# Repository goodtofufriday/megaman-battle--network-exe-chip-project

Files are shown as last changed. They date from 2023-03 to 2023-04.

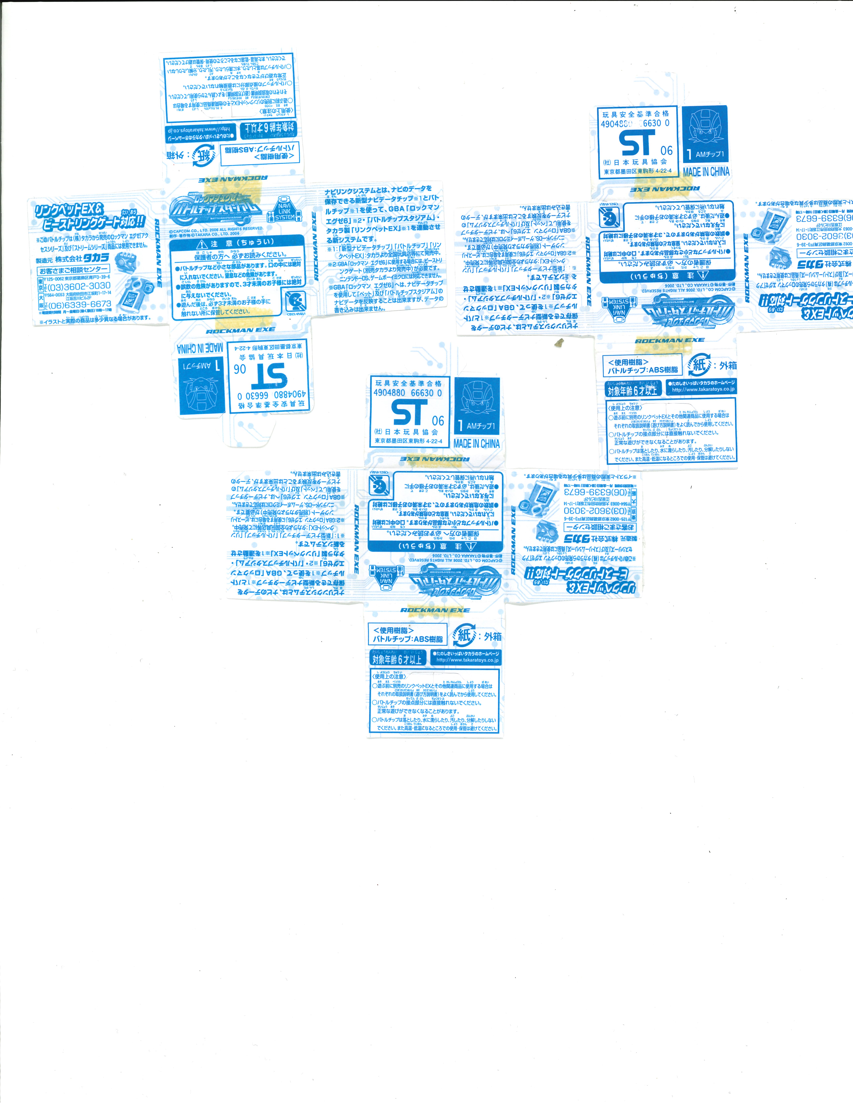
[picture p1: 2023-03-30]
EXE 6 Link Chips/Link BCS Paper Boxes/20230327121442341_0001.jpg

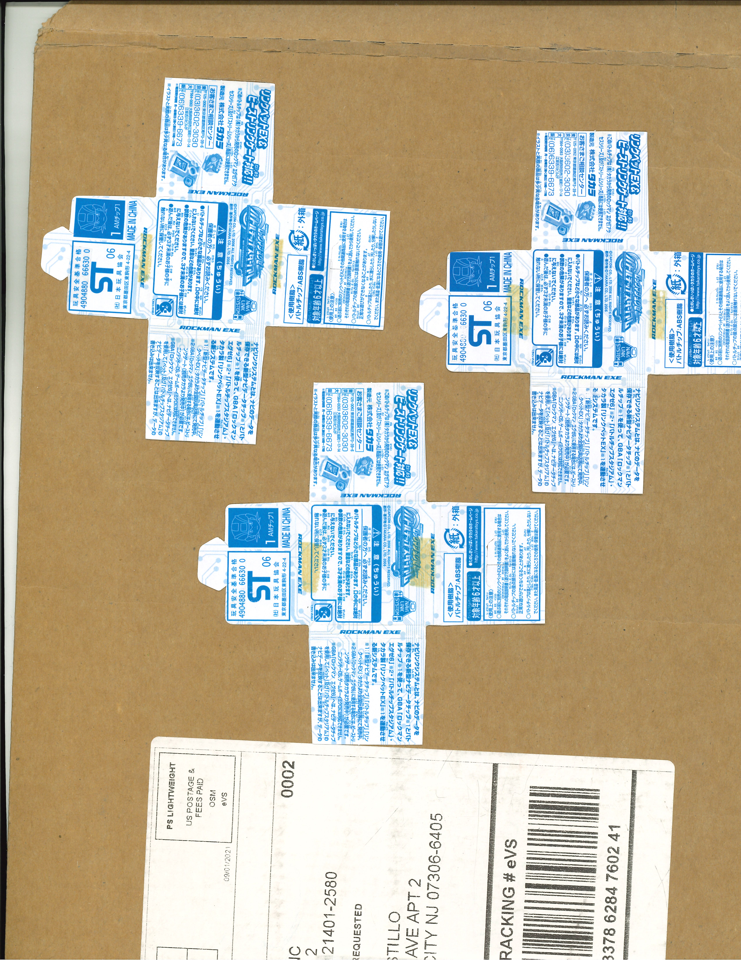
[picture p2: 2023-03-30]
EXE 6 Link Chips/Link BCS Paper Boxes/20230327121752596_0001.jpg

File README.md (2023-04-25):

# Megaman Exe Chip Project

This project started in 2018 when I found that the aftermarket prices of some battle chips were insane. It started with what I call the dip chips. Chips with dip switches on them that allow you to use ANY chip that was produced, and many that weren't.

It expanded to include the Link Navi chips. These chips can now be set to any level desired.

Then expanded further to produce all the chips that never got a physical release.

All pcbs were made in eagle and can be modified. Use the Blank chips as a base to create other chips not included in this project.

This is here just to help with Japanese SEO バトルチップ バトルチップ

## Whats left to do?

- [ ] Link Chip labels

- [ ] Link Chip Navi labels

- [ ] Progress Chip labels

## Dip Chips

These chips can become every chip in the game by turning a series of small switches on or off. The excel doc has every possible combination for the switches, and what chip those combinations activate for what game.

There is one dip chip that works for both exe 4 and exe 5 pets and gates. There is another for Link pets and gates. This had to be made sperate as there is one more pin, making it physically larger.

## Chip Pinouts

The Dip Switch combinations for all chips, and starforce barcodes for reprinting cards can be found [here.](https://docs.google.com/spreadsheets/d/1beCqi77os6HziWFO5Ia3u95-WQ1cv9IMDcv7cEDRxCU/edit#gid=0) 

I also have the excel uploaded in the git.

The custom parts folder has Eagle libaries for the pins on each series of chips. Add these files into your libraries folder for Eagle in "My Documents".

## Exe 6 Link Navis Chips

Eeprom used is an Atmel 24C08AN SOIC. Do not buy the tsop verion. They are physically different.

The chip can be programmed cheaply with a tl866 programmer. 

See the excel sheet for what Hex values to modify to change the Navi and its level.

## "Restored" Chips

- [ ] Patch for exe/bn 4 allows Duo and GrandPrix Power to work with physical chips.

- [ ] Exe 6 english patch allows 5 additional dark chips to work with physical chips.

## Infinite Chips

- [ ] These chips have all pins connected. You can cut traces for the pins you dont need to get the chip you want. 

- [ ] Standalone chips should be printed at dip chip thickness.

## Unreleased Reproduced Chips

This is the list of chips that were never physically made by capcom/takara but DO work in game as physical chips. You can make/buy these and use them as normal chips.

EXE 4

- [ ] 028 - Life Sync / ライフシンクロ (No JP Release)
- [ ] 263 – Burnerman / バーナーマン
- [ ] 305 - Grand Prix / グランプリ
- [ ] 308 - Signal Red / シグナルレッド
- [ ] 311 – Duo / デューオ (With patch)
- [ ] 312 - GrandPrix Power / グランプリパワー (With patch)

EXE 5 

- [ ] 544 - GunDelSol / ガンデルソル
- [ ] 545 - GunDelSol 2 / ガンデルソル 2
- [ ] 546 - Gun Del Sol 3 / ガンデルソル 3
- [ ] 727 - Otenko Sama / オテンコサマ
- [ ] 731 - Gun Del Sol EX / ガンデルソル EX
- [ ] 790 - Django / ジャンゴ
- [ ] 791 - Django SP / ジャンゴ SP
- [ ] 792 - Django DS / ジャンゴ DS
- [ ] 843 - Roll Navi / ロールナビ
- [ ] 844 - Gutsman Navi / ガッツマンナビ
- [ ] 845 - Windman Navi / ウインドマンナビ
- [ ] 847 - Fireman Navi / ファイアマンナビ
- [ ] 848 - Thunderman Navi / サンダーマンナビ
- [ ] 851 - Metalman Navi / メタルマンナビ
- [ ] 852 - Junkman Navi / ジャンクマンナビ
- [ ] 853 - Aquaman Navi / アクアマンナビ
- [ ] 854 - Woodman Navi / ウッドマンナビ

EXE 6

- [ ] 017 - GunDelSol 3 / ガンデルソル 3
- [ ] 026 - Train Arrow 3 / トレインアロ 3
- [ ] 046 - Heat Dragon  / ヒートドラゴン
- [ ] 067 - Bug Bomb / バグボム
- [ ] 076 - Flame Sword / フレイムソード  
- [ ] 128 - Air Wheel 3 / エアホイール 3
- [ ] 147 - Discord / ディスコード
- [ ] 162 - Panel Steal / パネルスチール
- [ ] 276 - Hakushaku EX / ハクシャク EX
- [ ] 277 - Hakushaku SP / ハクシャク SP
- [ ] 278 - Django / ジャンゴ
- [ ] 279 - Django V2 / ジャンゴ V2
- [ ] 280 - Django V3 / ジャンゴ V3
- [ ] 291 - Dark Tornado / ダークトルネード (With EXE 6 ENG Patch)
- [ ] 292 - Dark Circle / ダークサークル (With EXE 6 ENG Patch)
- [ ] 293 - Dark Meteors / ダークメテオ (With EXE 6 ENG Patch)
- [ ] 294 - Dark Lance / ダークランス (With EXE 6 ENG Patch)
- [ ] 295 - Dark Wide / ダークワイド (With EXE 6 ENG Patch)
- [ ] 313 - Falzer  / ファルザー

## Applications Used

- [ ] Eagle PCB

- [ ] InkScape

## Printing PCBs

I use pcbway to make my pcbs at the desired thickness. Eagle board files must be converted to gerbers.

- [ ] Chips that go inside shells need to be printed at 0.8mm thickness - I use oshpark for this instead of pcbway

- [ ] Exe4/5 chips need to be printed at 2mm

- [ ] Exe6 chips need to be printed at 2.4mm

- [ ] Plug-in pet print at 2.2mm

## Making the numbers for chips - DXF files

For what ever reason, Eagel does not support system installed fonts. And we need a special font to match real chips.

It took me 5 hours of search fonts to find a perfect match. It is in the Numbers folder.

- [ ] Use Inkscape: Set fill to none. Set stroke to something. Doesn't matter much how full. 
- [ ] Type out number in font. Select all. 
- [ ] Path - object to path
- [ ] Object - ingroup
- [ ] Path - break apart
- [ ] Save as dxf

- [ ] In eagle 
- [ ] Import dxf.
- [ ] Struggle with x/y parameters. (I have included paramters that work with my board files)
- [ ] Delete lines in middle of the rectangles/number segments. 
- [ ] Separate the segments just enough so that they aren't touching. 
- [ ] Convert each segment to polygon (use replace)
- [ ] Select them all
- [ ] Ratsnest

Then just do that for every number...
Oh and for any number that has a 1 in the first or second spot you need to manually adjust the adjacent numbers to be closer to the one. 
This font has a large box for 1 for some reason.
Best option IMO is to use and 8 and remove the sections you dont need

## Sticker Labels

I used StickerApp and the labels came out with the correct color and texture.

## Special Thanks

- [ ] Eurasia_M - Helped spark my internest into this project, along with his massive wealth of knowledge on battle chips, testing.

- [ ] NettoHikari of ScilabSecrets.com - Wealth of Knowledge on battle chips, PET dip chip testing. Finding StickerApp Manufacturer.

- [ ] [Gateonine](https://www.reddit.com/user/Gateonine) - All Chip Shell model,  Pet emulation testing

- [ ] Enzan - Plug-in Pet codes

- [ ] StackOverflow0x - Exe 4/5/6 Labels

- [ ] AtomizerZero - Helped create the beta version of the dip chip based on my instructions. Used this to learn how to use Eagle.

- [ ] Seabit - Testing

- [ ] Yukki/Twilight - Testing

- [ ] Prof9 - Patch for exe/bn 4

- [ ] EXEGUY11 - ENG patch for Exe 6

- [ ] Zarch - Further research into the Link Navis and making a PET emulator on pc. See his project [here.](https://gitlab.com/zarcha/link-analyzer)

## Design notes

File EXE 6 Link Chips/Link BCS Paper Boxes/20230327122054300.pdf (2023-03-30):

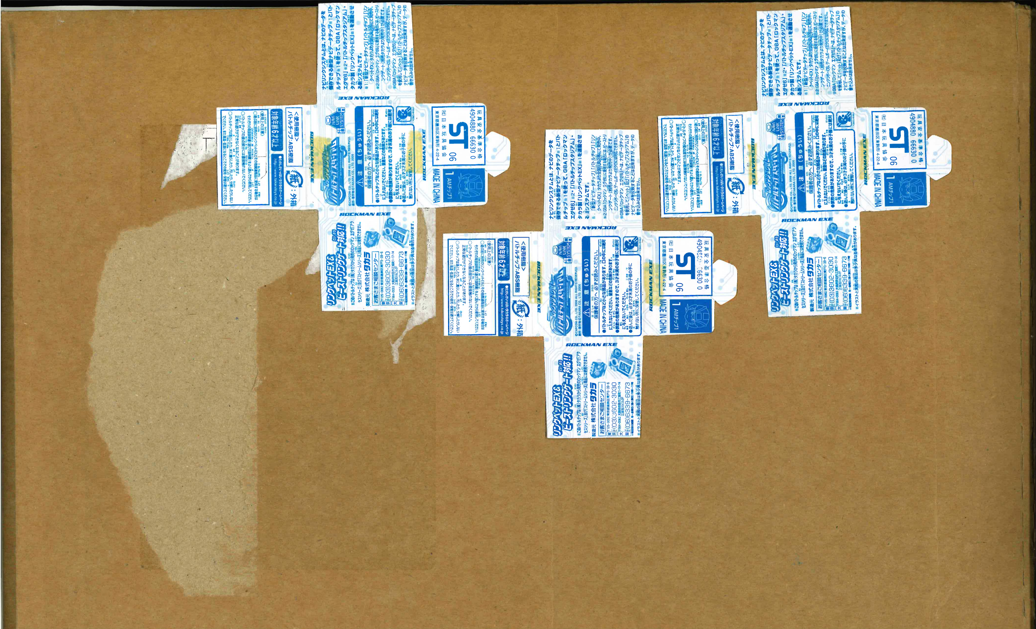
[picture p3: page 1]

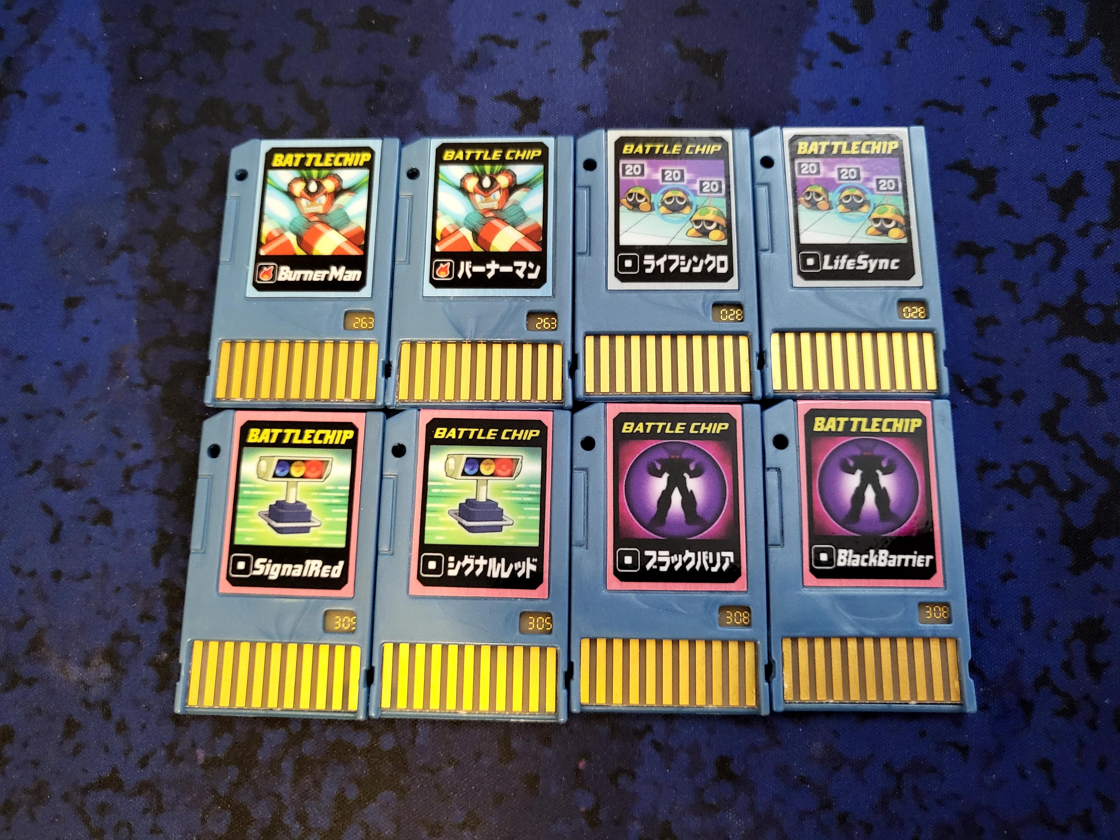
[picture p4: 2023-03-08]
Advance_Chips.jpg

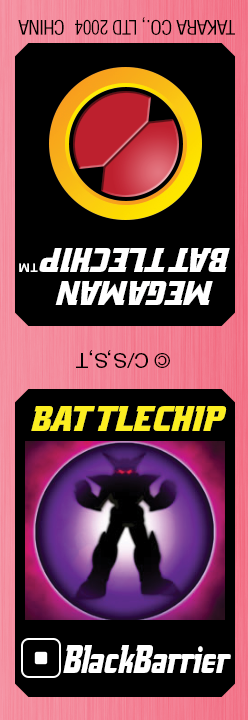
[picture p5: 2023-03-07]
EXE 4 Advance Chips/Advance Chip Missing Labels/Black_Barrier_ENG.png

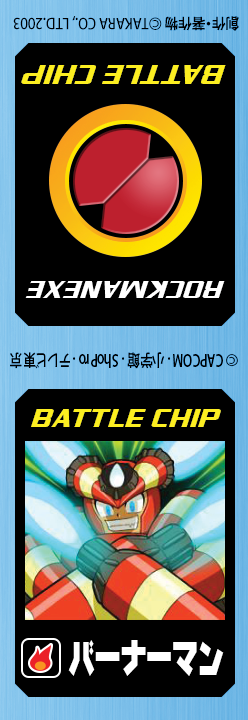
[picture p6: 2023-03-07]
EXE 4 Advance Chips/Advance Chip Missing Labels/BurnerMan_JPN.png

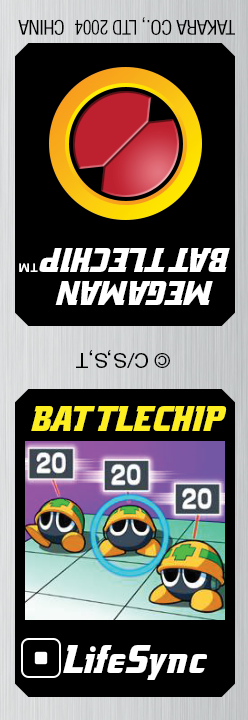
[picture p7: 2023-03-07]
EXE 4 Advance Chips/Advance Chip Missing Labels/Life_Sync_ENG.png

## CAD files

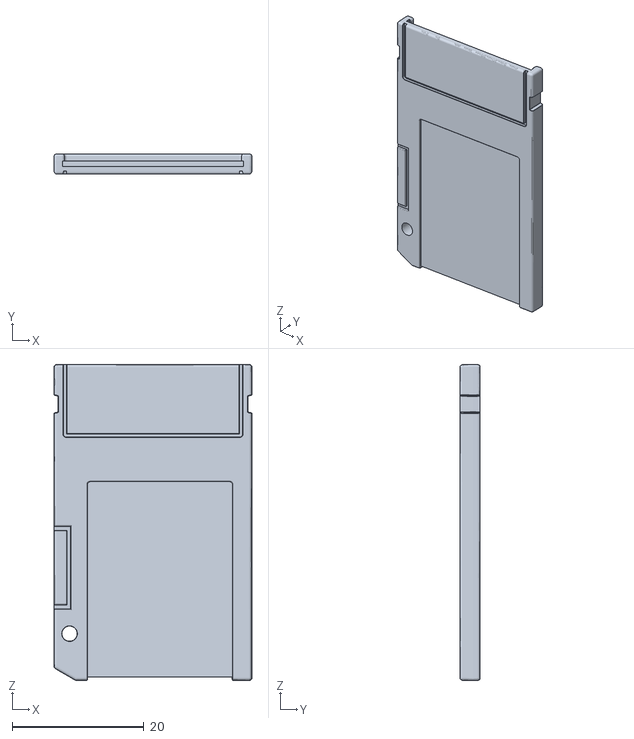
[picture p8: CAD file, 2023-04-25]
EXE 4 Advance Chips/Advance Chip Shell/Advanced Chip Rev -.STL
30.0 x 3.10 x 47.9

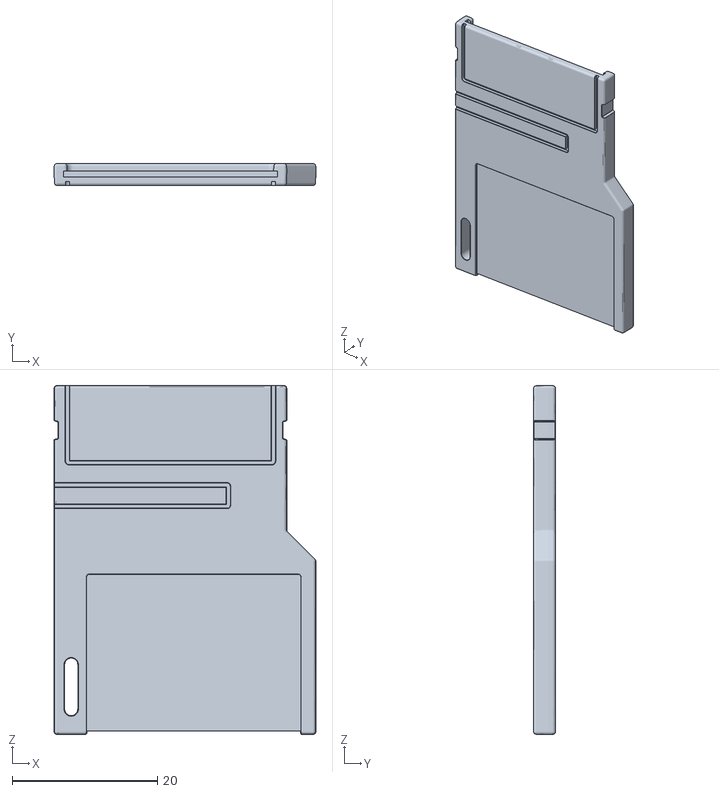
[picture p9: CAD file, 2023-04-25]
EXE 5 Progress Chips/Progress Chip Shell/Progress Chip REV-.STL
36.0 x 3.05 x 48.0

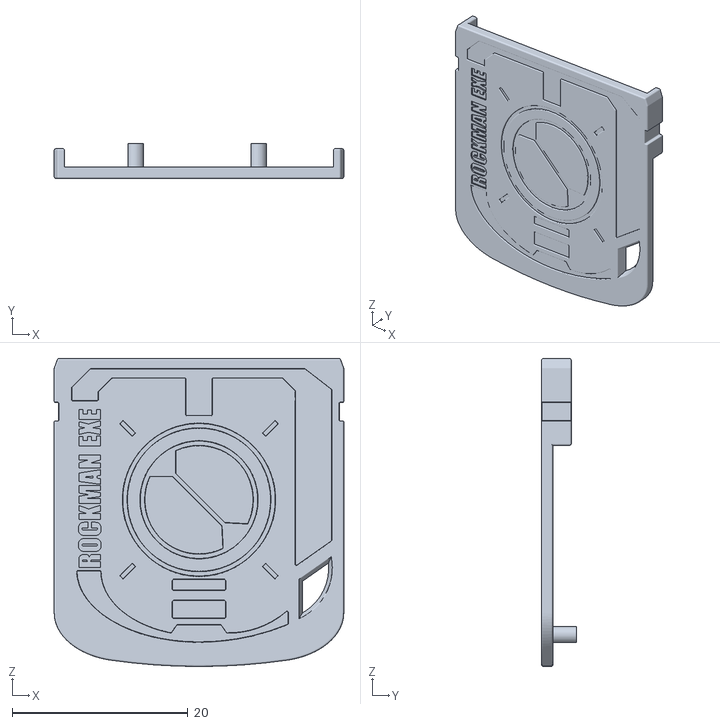
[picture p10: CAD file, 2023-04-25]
EXE 6 Link Chips/Link Chip Shell/Navi Shell/Link Navi Chip Bottom REV-.STL
33.0 x 4.00 x 35.1

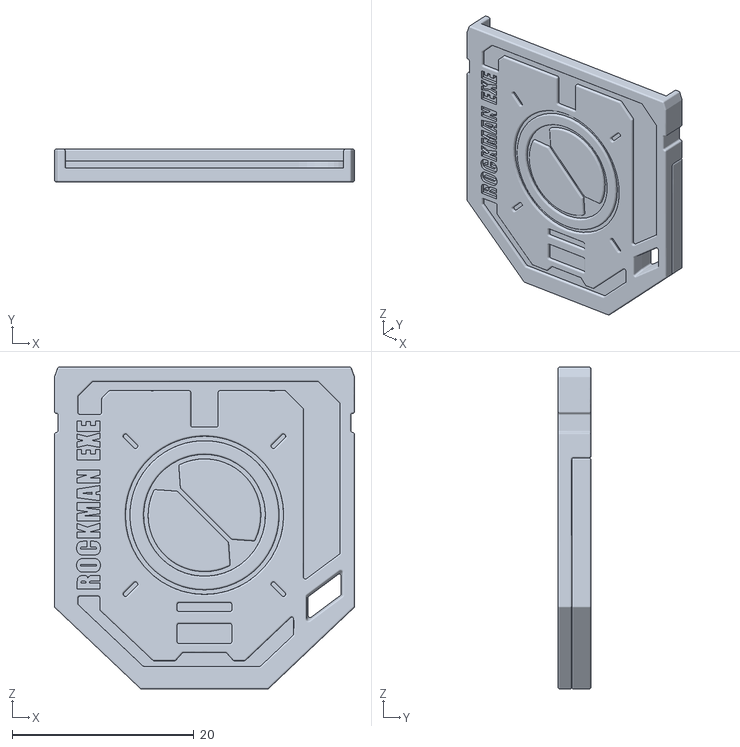
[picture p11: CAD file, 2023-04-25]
EXE 6 Link Chips/Link Chip Shell/Single Model/Link Chip REV-1.STL
33.0 x 3.60 x 35.4

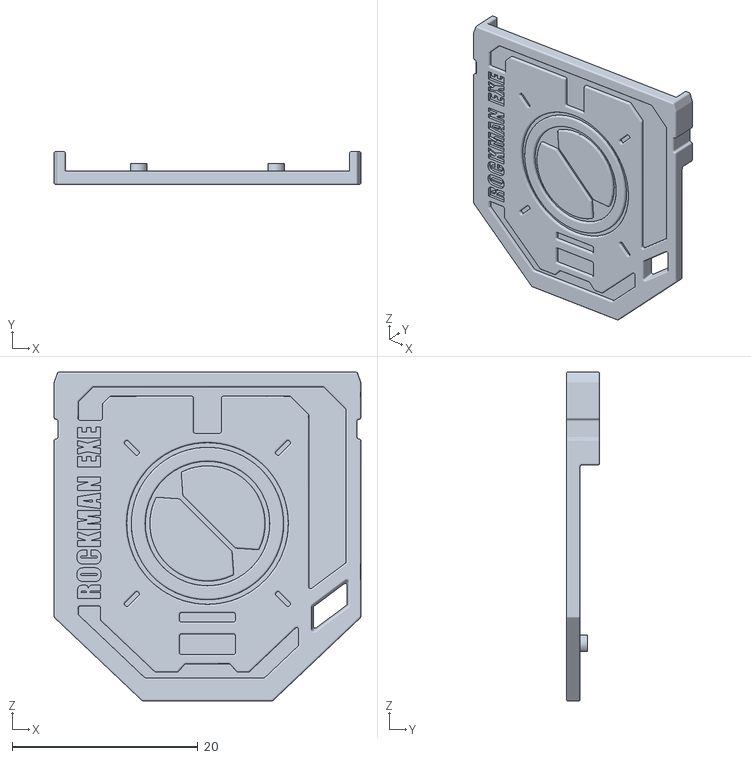
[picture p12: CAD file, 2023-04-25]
EXE 6 Link Chips/Link Chip Shell/Split Model/Link Chip Separate Bottom REV-1.STL
33.0 x 3.60 x 35.4

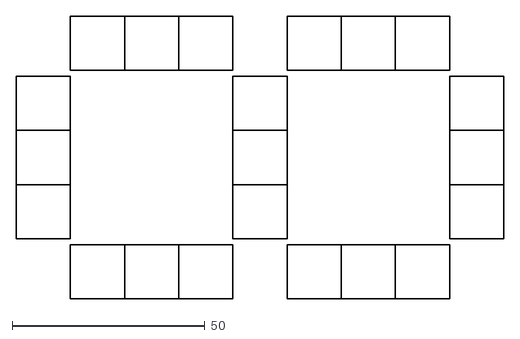
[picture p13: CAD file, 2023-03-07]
Numbers/infinite.dxf
126.6 x 73.3

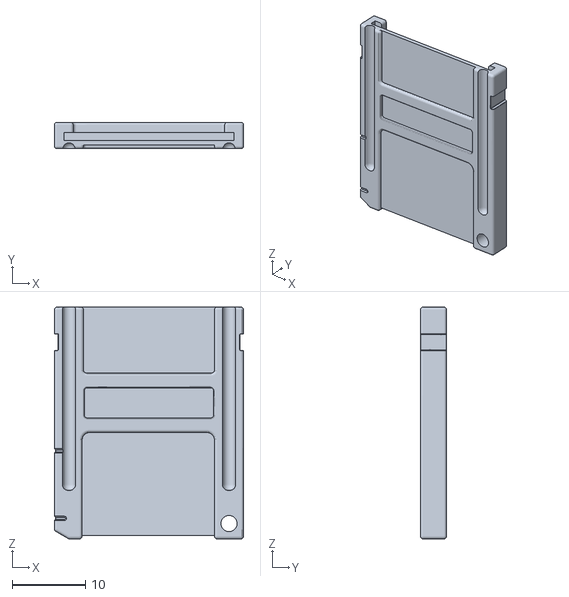
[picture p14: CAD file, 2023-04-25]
Plug-In Pet/Plug-In Pet Shell/Plugin Chip REV-.STL
25.8 x 3.60 x 31.6

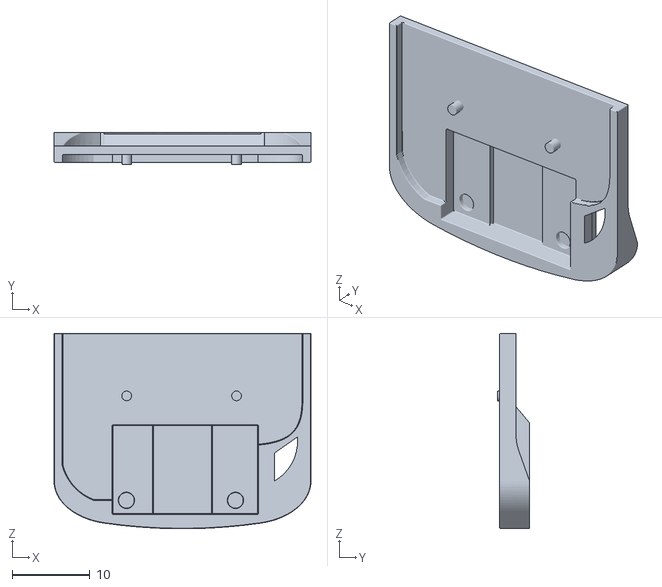
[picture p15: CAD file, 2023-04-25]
EXE 6 Link Chips/Link Chip Shell/Navi Shell/Link Navi Chip Top REV-.STL
33.0 x 4.15 x 25.1

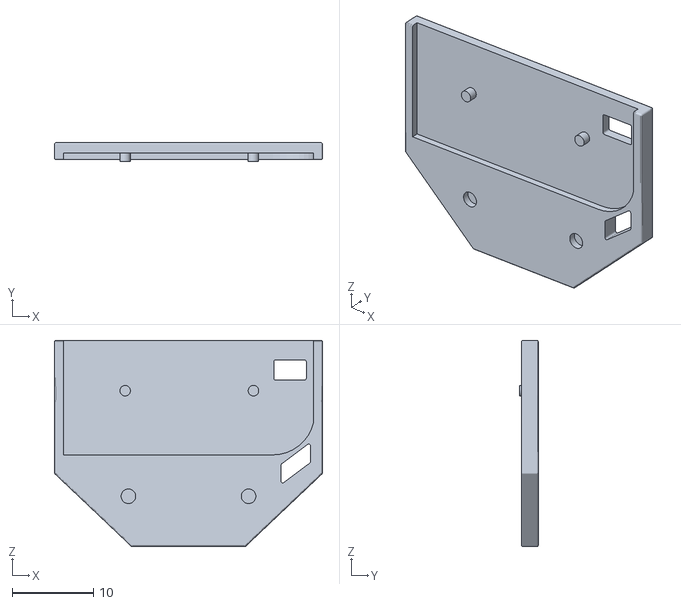
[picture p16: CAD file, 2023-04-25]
EXE 6 Link Chips/Link Chip Shell/Split Model/Link Chip Separate Top REV-1.STL
33.0 x 2.30 x 25.4

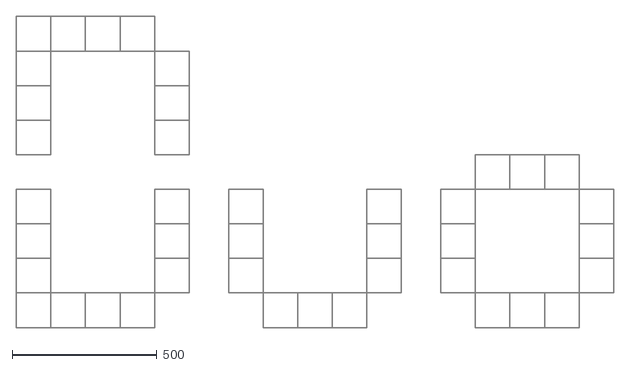
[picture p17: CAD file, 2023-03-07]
Numbers/Duo.dxf
2062.8 x 1074.4

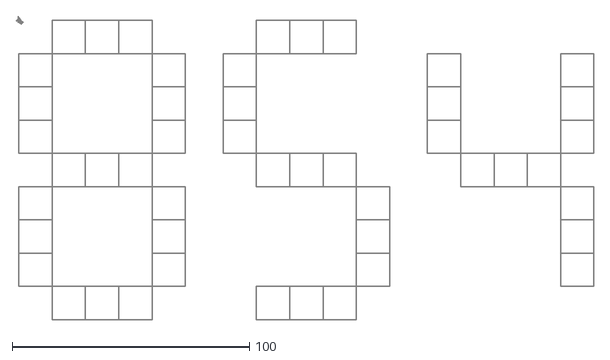
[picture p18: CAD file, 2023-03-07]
Numbers/854.dxf
243.7 x 128.0

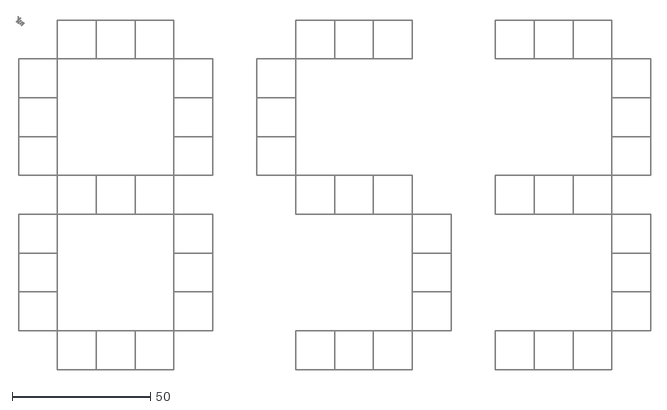
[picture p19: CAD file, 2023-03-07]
Numbers/853.dxf
229.3 x 127.7

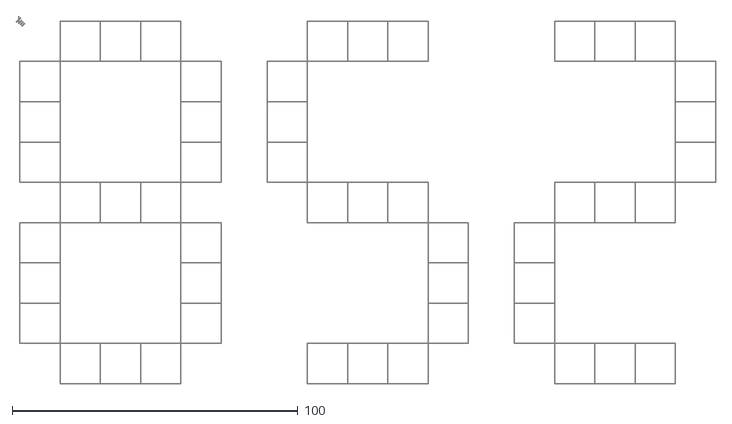
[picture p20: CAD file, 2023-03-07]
Numbers/852.dxf
244.6 x 128.5

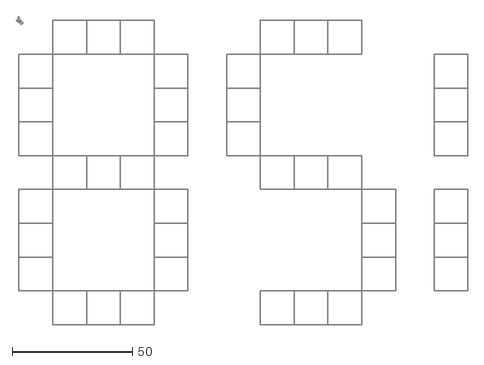
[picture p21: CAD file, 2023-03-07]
Numbers/851.dxf
187.5 x 128.0

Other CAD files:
Numbers/848.dxf
Numbers/847.dxf
Numbers/845.dxf
Numbers/844.dxf
Numbers/017.dxf
Numbers/026.dxf
Numbers/028.dxf
Numbers/046.dxf
Numbers/067.dxf
Numbers/076.dxf
Numbers/128.dxf
Numbers/147.dxf
Numbers/162.dxf
Numbers/263.dxf
Numbers/276.dxf
Numbers/277.dxf
Numbers/278.dxf
Numbers/279.dxf
Numbers/280.dxf
Numbers/291.dxf
Numbers/292.dxf
Numbers/293.dxf
Numbers/294.dxf
Numbers/295.dxf
Numbers/305.dxf
Numbers/308.dxf
Numbers/311.dxf
Numbers/312.dxf
Numbers/313.dxf
Numbers/544.dxf
Numbers/545.dxf
Numbers/546.dxf
Numbers/727.dxf
Numbers/731.dxf
Numbers/790.dxf
Numbers/791.dxf
Numbers/792.dxf
Numbers/843.dxf

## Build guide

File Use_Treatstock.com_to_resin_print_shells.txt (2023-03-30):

I personally recommend this printerer.

https://www.treatstock.com/c/3d-printer-filaments

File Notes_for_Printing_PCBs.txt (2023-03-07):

Chips that go inside shells need to be printed at 0.8mm thickness

Exe4/5 dip chips need to be printed at 2mm

Exe6 dip chips need to be printed at 2.4mm

Plug-in pet print at 2.2mm

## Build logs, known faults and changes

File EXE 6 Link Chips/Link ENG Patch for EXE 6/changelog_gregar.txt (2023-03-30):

v1.0 - All menu text, graphics, chip text, navi names, virus names, area names, BBS text, Crossover Battle 2 text,
chip shop text, chip trader text, mystery data access text, Poem & Humor text, and item names changed/translated.
The first few cutscenes are translated up until after Iris is saved. Most of the text in Asterland is translated 
except for NPCs (excluding Tab and Mr.Famous). Prof. 9's custom e-card marker and no panic music added. The Tornado
chip glitch is fixed, and the name edit limit is expanded to 8 characters. Cheats added for Gregar SP link navis.
Dark chips and BLG chips added (the same cheats from before work as well). The same modded number trader prizes are
added, with the exception of Falzar X, which is now Gregar X. Mail sort options changed. Should be fully compatible 
with my Falzar patch for trading, netbattling etc.

v1.1 - Fully modified into english. It is now identical to the Falzar patch in terms of completion, and two patch
files are included as well with/without the Wii U features.

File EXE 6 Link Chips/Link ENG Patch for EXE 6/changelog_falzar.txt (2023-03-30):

v1.0 - Initial release

v1.1 - Added 3 new prizes to number trader. Fixed up a text error that occured
during the "Can't open safe" request bbs mission. Removed the obtaining of
DarkThnd after beating Mr.Quiz. Added 5 new dark chips. Reverted all instances
of KillrMan back to EraseMan.

v1.2 - Fixed major bug with wireless adapter netbattles that caused client's chip 
selection screen to display all non-working chips.

v1.3 - Fixed glitch that caused the game to freeze when talking to generic brown 
Navi in Sky Area 1 during GroundMan class. Corrected PMD unlock text displaying
cave speak.

v1.4 - Translated text I missed in Kaizou/Custom screen that appears when Select
is pressed. DblBeast & both Cybeast chips descriptions changed to more closely match the official 
japanese description. Fixed up a few lines of e-Card receive text (check provided
screenshots). Changed every instance of "TheCount" to "Count". Added replaced japanese virus
battler prizes to number trader (AirSpin1 F, AntiDmg R, Geddon L). Added chip images and
icons to the 4 Arm Change chips and Sync Trigger. Fixed range check for "." character, so now 
mugshots don't look like they're still talking when something like "......." appears. All mail
sort options changed to the ones from BN6. Fixed a small spacing glitch in the credits, where the
M and G weren't aligned properly underneath the S. Number trader "OK" and name edit table bracket
alignments are now fixed. Name entry limit has been expanded to 8, and the placeholder character
has been fixed as well. Fixed Tornado chip glitch that caused it to do more damage when used over
an elemental panel, and had a White Capsule applied to it. Fixed glitch where the last 2 tiles of
Cstmzing and Interval graphics would stay on screen randomly. Added a marker that is used with
Prof. 9's custom e-cards, so when the cards are used with my patch, english text is displayed instead
of japanese!

v1.5 - ProtoMan SP can now be fought after clearing the first 25 BBS missions, and pressing select at
the request board. Game crashing bug from previous Tornado chip fix has been corrected. Updated artwork
for BLG chips.

v1.6 - Graveyard 2 cybertree and cybercloud text glitches corrected, and the Undernet 3 door is now translated
properly and opens with a Machine Sword chip.

v1.7 - Polished up the DarkThnd fix from v1.1 that caused the library to crash when checking the 30th entry, and
made DolThdr E appear in the chip order screen without having obtained the chip first.

v1.8 - Two patches are available now, one with and one without the Wii U features for obtaining all secret chips and
10 extra BBS request. Changed up the credits a bit and changed "PuzzlArm" to "PulseArm".

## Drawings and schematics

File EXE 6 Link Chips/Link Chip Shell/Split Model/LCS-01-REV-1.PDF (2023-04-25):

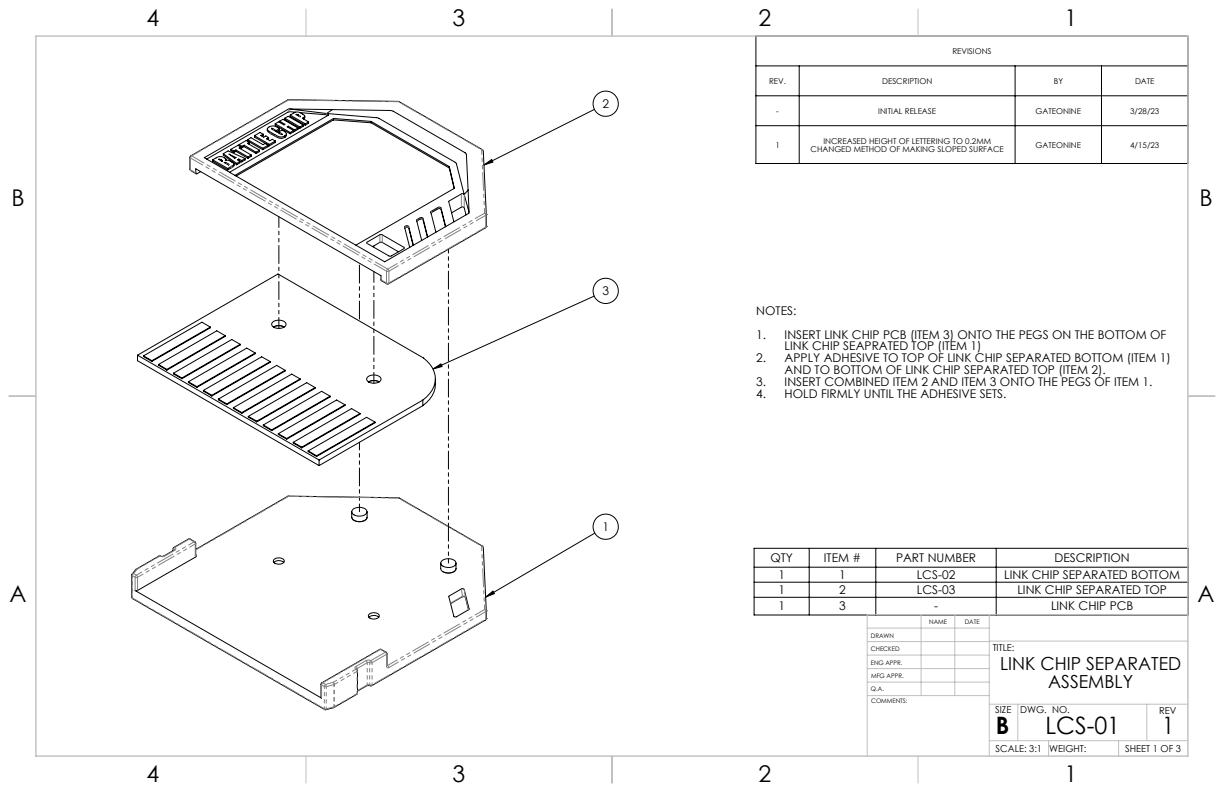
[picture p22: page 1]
QTY; ITEM #; PART NUMBER; DESCRIPTION 1; LCS-02; LINK CHIP SEPARATED BOTTOM 1; LCS-03; LINK CHIP SEPARATED TOP 1; LINK CHIP PCB

REV. | INCREASED HEIGHT OF LETTERING TO 0.2MM INITIAL RELEASE DESCRIPTION | GATEONINE BY | 3/28/23 1 DATE -

CHANGED METHOD OF MAKING SLOPED SURFACE | GATEONINE | 4/15/23

NOTES:
1. INSERT LINK CHIP PCB (ITEM 3) ONTO THE PEGS ON THE BOTTOM OF
LINK CHIP SEAPRATED TOP (ITEM 1)
2. APPLY ADHESIVE TO TOP OF LINK CHIP SEPARATED BOTTOM (ITEM 1)
AND TO BOTTOM OF LINK CHIP SEPARATED TOP (ITEM 2).
3. INSERT COMBINED ITEM 2 AND ITEM 3 ONTO THE PEGS OF ITEM 1.
4. HOLD FIRMLY UNTIL THE ADHESIVE SETS.

NAME | DATE
CHECKED | | | TITLE: LINK CHIP SEPARATED ASSEMBLY

DRAWN

ENG APPR.
MFG APPR.
Q.A.

SIZE B | DWG. NO. LCS-01 | REV 1

SCALE: 3:1 | WEIGHT: | SHEET 1 OF 3

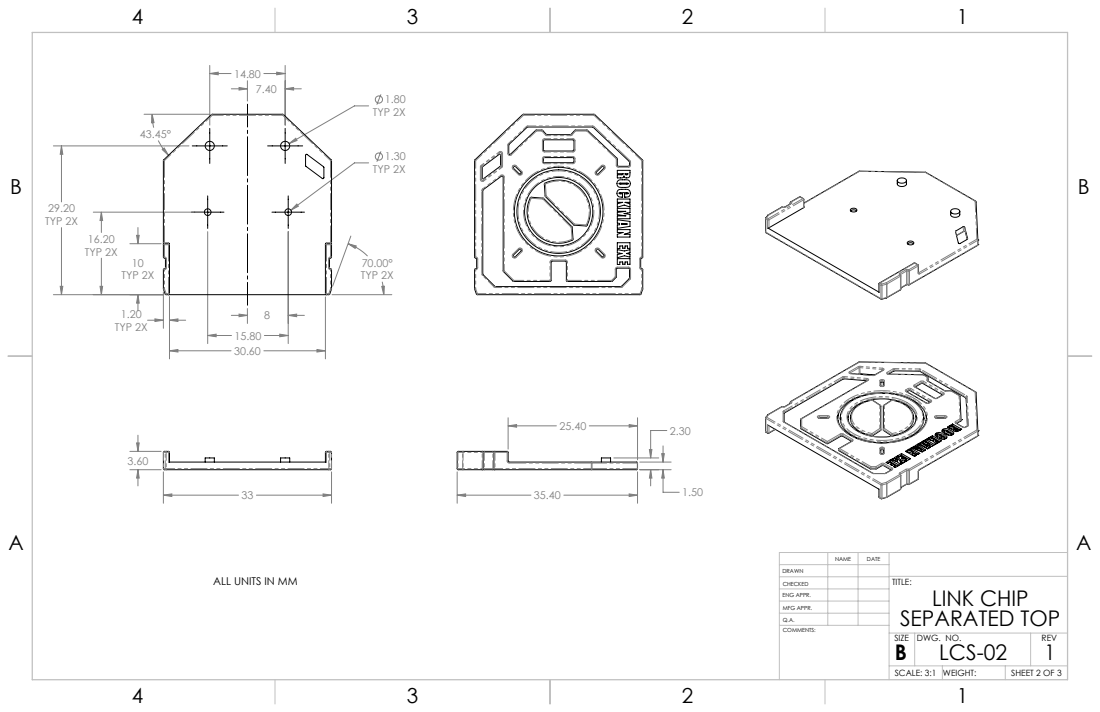
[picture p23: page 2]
TYP 2X; DWG. NO.; REV

NAME | DATE
CHECKED | | | TITLE: LINK CHIP SEPARATED TOP

DRAWN

ALL UNITS IN MM

ENG APPR.
MFG APPR.
Q.A.

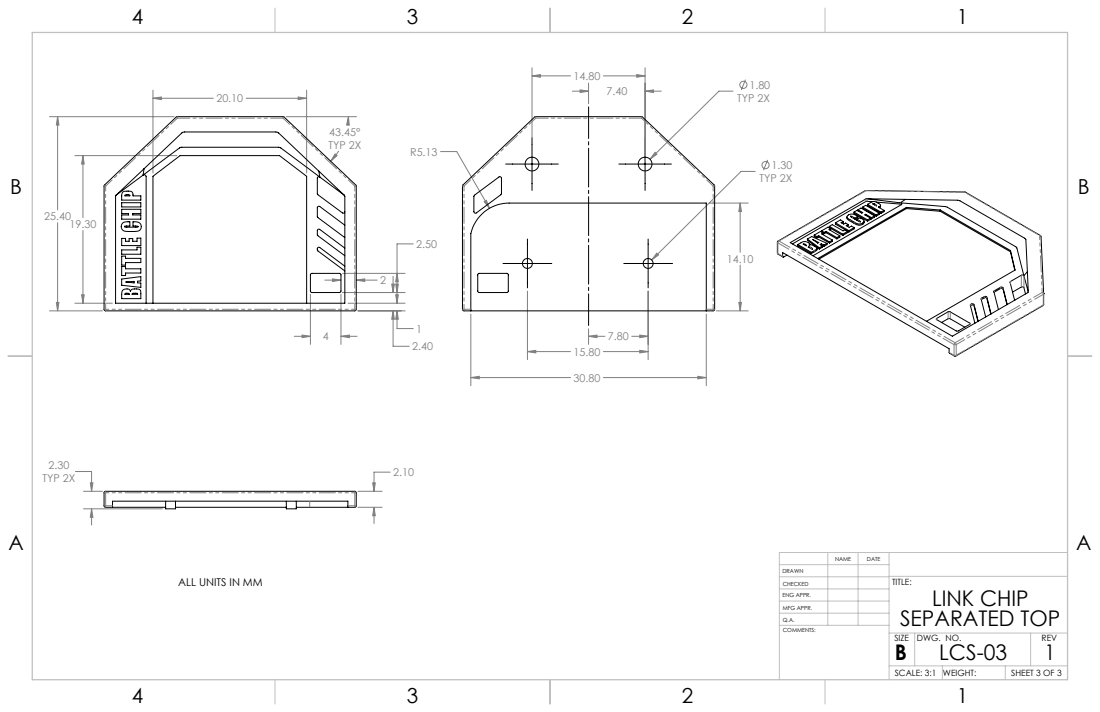
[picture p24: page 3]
2.10 2.30 TYP 2X; TYP 2X; DWG. NO.; REV

NAME | DATE
CHECKED | | | TITLE: LINK CHIP SEPARATED TOP

DRAWN

ALL UNITS IN MM

ENG APPR.
MFG APPR.
Q.A.

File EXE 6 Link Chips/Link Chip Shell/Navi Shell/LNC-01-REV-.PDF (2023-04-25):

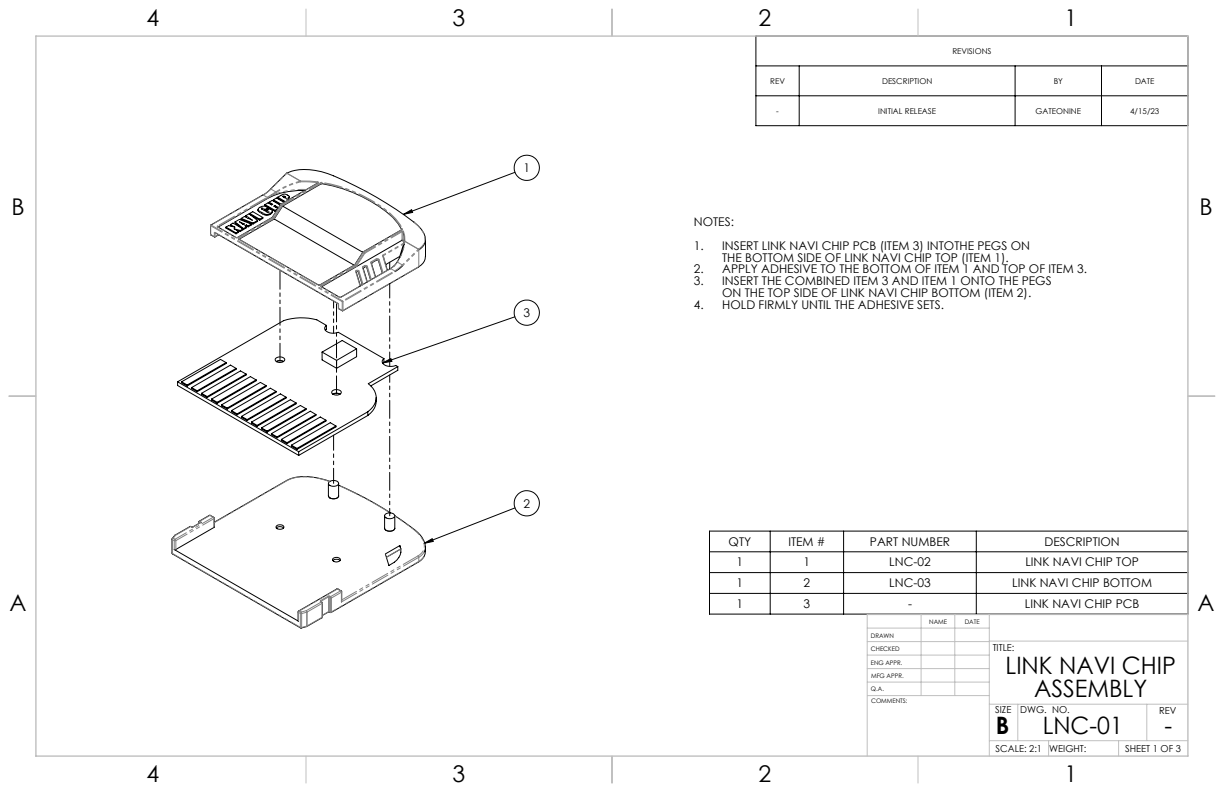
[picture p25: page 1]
LINK NAVI CHIP PCB; LNC-01; - SCALE: 2:1; WEIGHT:; SHEET 1 OF 3; DWG. NO.; REV

REVISIONS

REV | DESCRIPTION | BY | DATE

- | INITIAL RELEASE | GATEONINE | 4/15/23

NOTES:
1. INSERT LINK NAVI CHIP PCB (ITEM 3) INTOTHE PEGS ON
THE BOTTOM SIDE OF LINK NAVI CHIP TOP (ITEM 1).
2. APPLY ADHESIVE TO THE BOTTOM OF ITEM 1 AND TOP OF ITEM 3.
3. INSERT THE COMBINED ITEM 3 AND ITEM 1 ONTO THE PEGS
ON THE TOP SIDE OF LINK NAVI CHIP BOTTOM (ITEM 2).
4. HOLD FIRMLY UNTIL THE ADHESIVE SETS.

QTY | ITEM # | PART NUMBER | DESCRIPTION
1 | 1 | LNC-02 | LINK NAVI CHIP TOP
1 | 2 | LNC-03 | LINK NAVI CHIP BOTTOM

NAME | DATE
CHECKED | | | TITLE: LINK NAVI CHIP ASSEMBLY

DRAWN

ENG APPR.
MFG APPR.
Q.A.

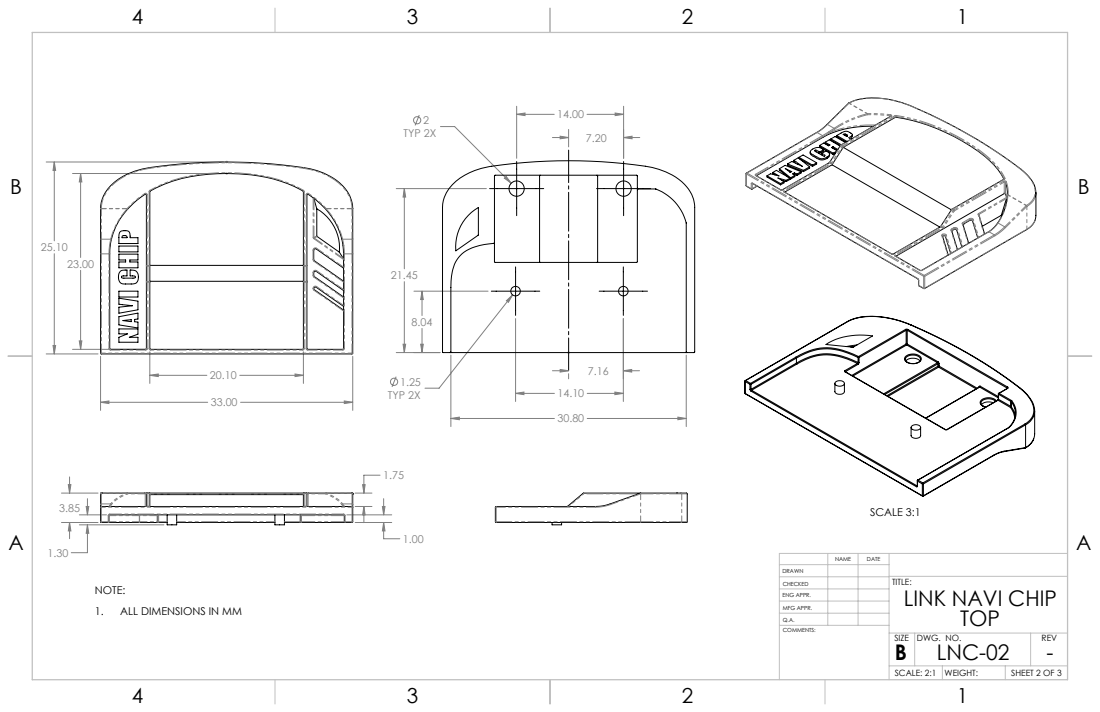
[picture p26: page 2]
TYP 2X; SCALE 3:1

NAME | DATE
CHECKED | | | TITLE: LINK NAVI CHIP TOP

DRAWN

NOTE:
1. ALL DIMENSIONS IN MM

ENG APPR.
MFG APPR.
Q.A.

SIZE B | DWG. NO. LNC-02 SHEET 2 OF 3 | REV - SCALE: 2:1

WEIGHT:

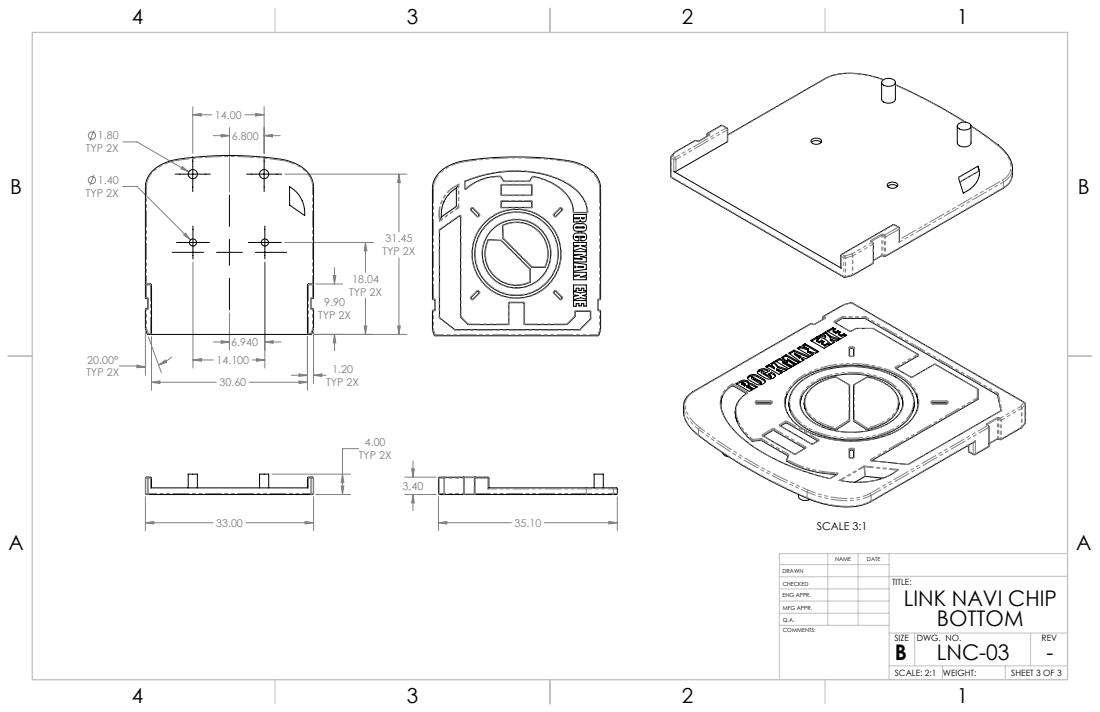
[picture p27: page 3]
TYP 2X; SCALE 3:1; LNC-03; - SCALE: 2:1; WEIGHT:; SHEET 3 OF 3; DWG. NO.; REV

NAME | DATE
CHECKED | | | TITLE: LINK NAVI CHIP BOTTOM

DRAWN

ENG APPR.
MFG APPR.
Q.A.

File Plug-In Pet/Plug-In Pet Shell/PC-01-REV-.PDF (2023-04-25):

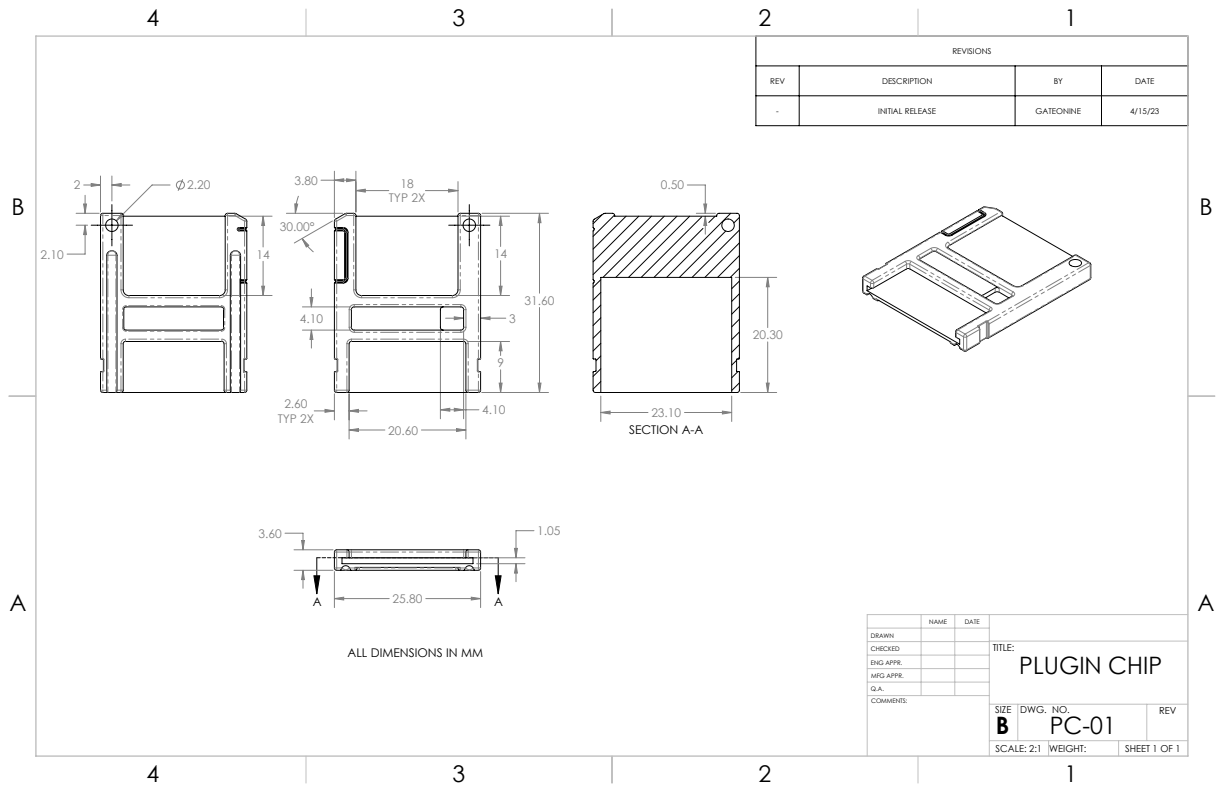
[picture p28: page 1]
TYP 2X; SECTION A-A

REVISIONS

REV | DESCRIPTION | BY | DATE

- | INITIAL RELEASE | GATEONINE | 4/15/23

NAME | DATE
CHECKED | | | TITLE: PLUGIN CHIP

DRAWN

ALL DIMENSIONS IN MM

ENG APPR.
MFG APPR.
Q.A.

SIZE B | DWG. NO. PC-01 | REV

SCALE: 2:1 | WEIGHT: | SHEET 1 OF 1

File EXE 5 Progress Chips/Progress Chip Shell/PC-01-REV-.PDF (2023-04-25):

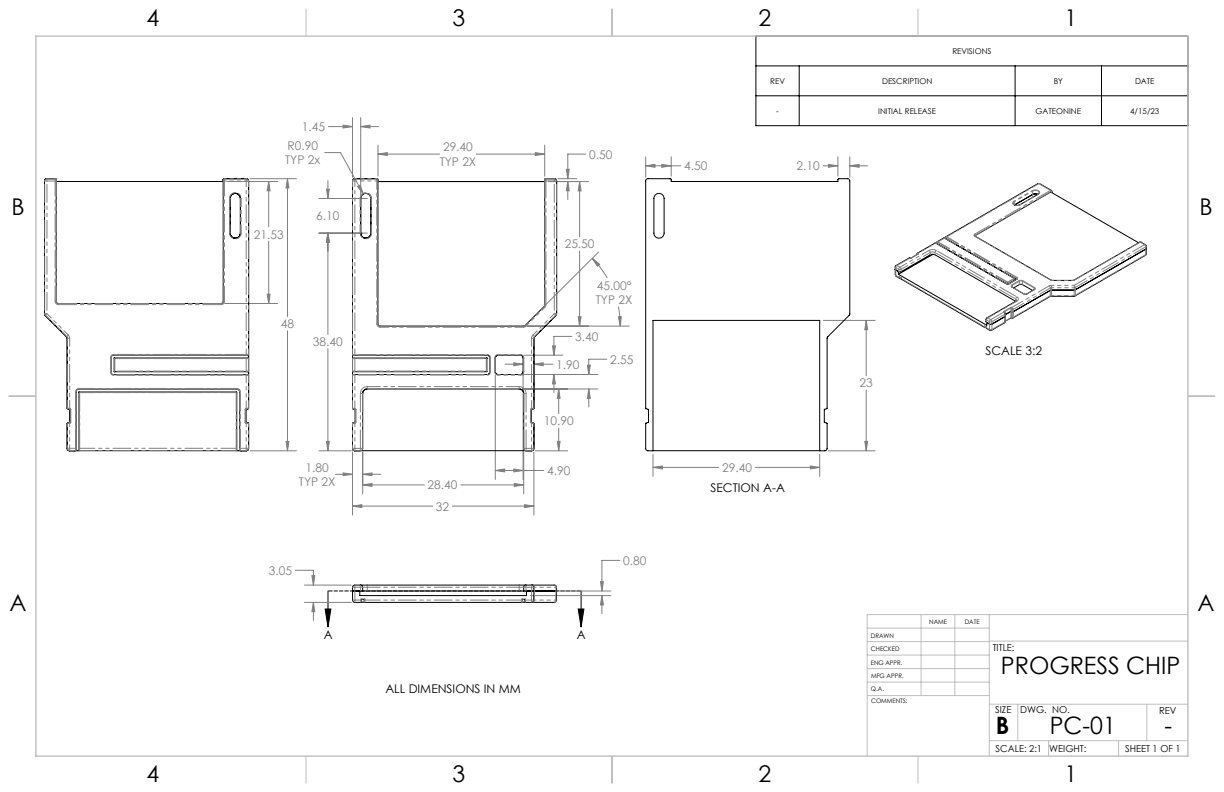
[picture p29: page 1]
TYP 2x; TYP 2X; SECTION A-A; SCALE 3:2; - SCALE: 2:1; WEIGHT:; SHEET 1 OF 1; DWG. NO.; REV

REVISIONS

REV | DESCRIPTION | BY | DATE

- | INITIAL RELEASE | GATEONINE | 4/15/23

CHECKED | TITLE: PROGRESS CHIP

ENG APPR.
MFG APPR.
Q.A.

ALL DIMENSIONS IN MM

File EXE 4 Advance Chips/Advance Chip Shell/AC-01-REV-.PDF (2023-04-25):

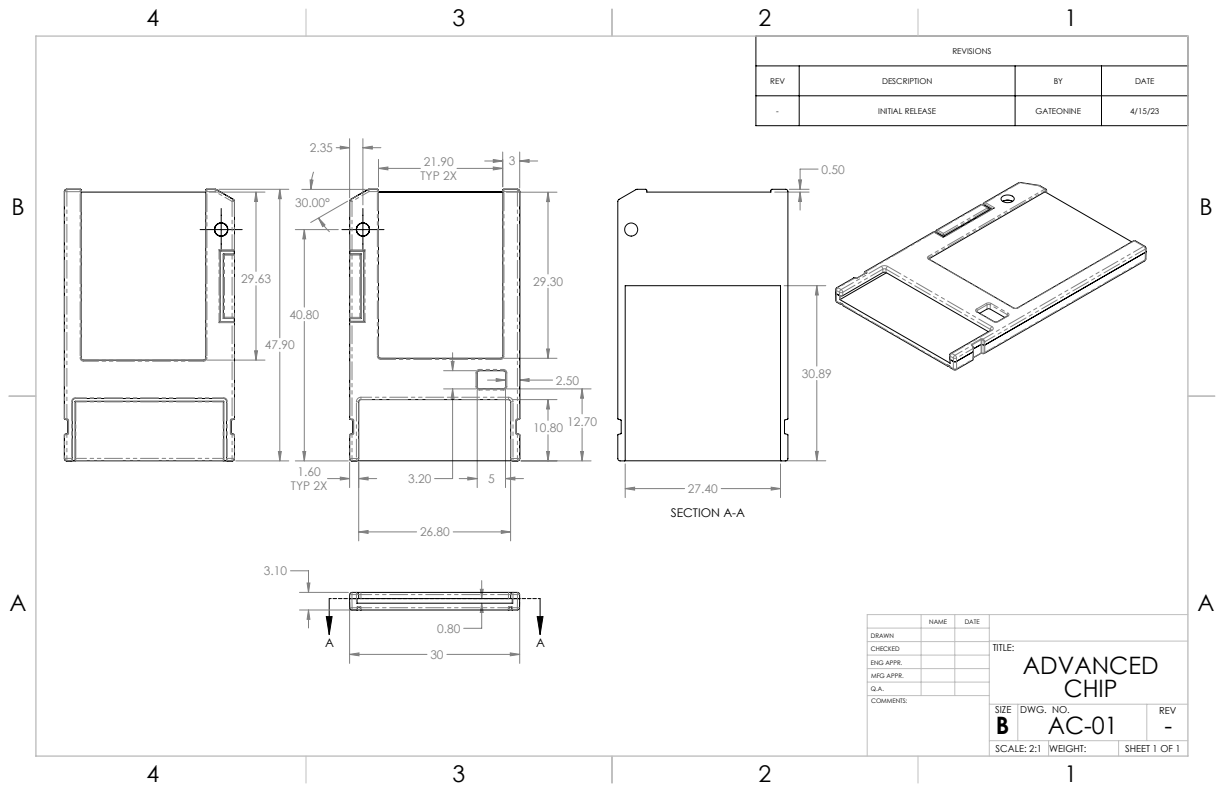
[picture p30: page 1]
TYP 2X; SECTION A-A; - SCALE: 2:1; WEIGHT:; SHEET 1 OF 1; DWG. NO.; REV

3 | REVISIONS

REV | DESCRIPTION | BY | DATE

- | INITIAL RELEASE | GATEONINE | 4/15/23

NAME | DATE
CHECKED | | | TITLE: ADVANCED CHIP

DRAWN

ENG APPR.
MFG APPR.
Q.A.

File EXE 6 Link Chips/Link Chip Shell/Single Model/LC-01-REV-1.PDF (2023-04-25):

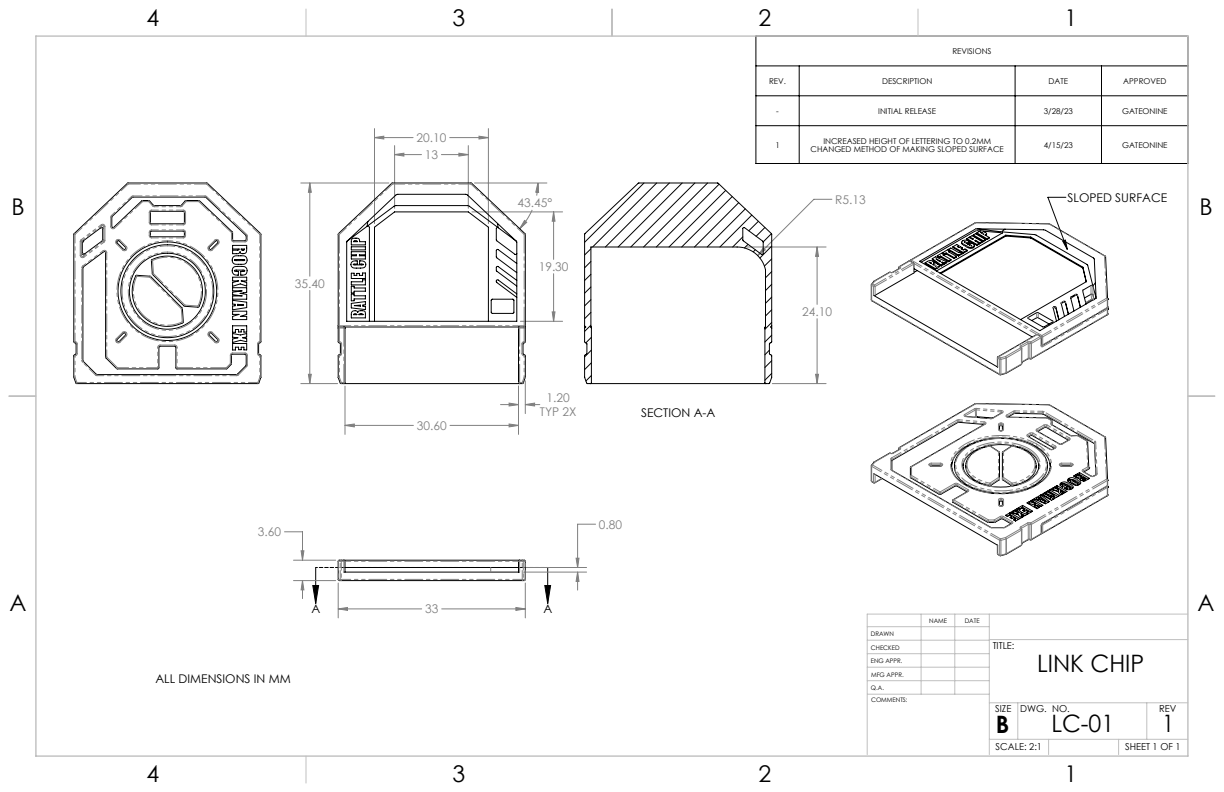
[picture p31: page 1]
TYP 2X; SLOPED SURFACE; SECTION A-A

REVISIONS

REV. | DESCRIPTION | DATE | APPROVED

- | INITIAL RELEASE | 3/28/23 | GATEONINE

1 | INCREASED HEIGHT OF LETTERING TO 0.2MM CHANGED METHOD OF MAKING SLOPED SURFACE | 4/15/23 | GATEONINE

NAME | DATE

DRAWN
CHECKED | | | TITLE: LINK CHIP

ENG APPR.
MFG APPR.
Q.A.

ALL DIMENSIONS IN MM

SIZE B | DWG. NO. LC-01 | REV 1

SCALE: 2:1 | | SHEET 1 OF 1

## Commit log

2023-03-07 Upload New File
    [tofu2.sch]
2023-03-20 Replace Django.brd
    [Django.brd]
2023-03-20 Replace falzar_curve_313.brd
    [falzar_curve_313.brd]
2023-03-20 Replace Djanso_DS_792.brd
    [Djanso_DS_792.brd]
2023-03-20 Replace Djanso_SP_791.brd
    [Djanso_SP_791.brd]
2023-03-20 Replace Gun_Del_Sol.brd
    [Gun_Del_Sol.brd]
2023-03-20 Replace Gun_Del_Sol_2.brd
    [Gun_Del_Sol_2.brd]
2023-03-20 Replace Gun_Del_Sol_3.brd
    [Gun_Del_Sol_3.brd]
2023-03-20 Replace Gun_Del_Sol_EX.brd
    [Gun_Del_Sol_EX.brd]
2023-03-20 Replace Navi_Aquaman.brd
    [Navi_Aquaman.brd]
2023-03-20 Replace Navi_Fireman.brd
    [Navi_Fireman.brd]
2023-03-20 Replace Navi_Gutsman.brd
    [Navi_Gutsman.brd]
2023-03-20 Replace Navi_Junkman.brd
    [Navi_Junkman.brd]
2023-03-20 Replace Navi_Metalman.brd
    [Navi_Metalman.brd]
2023-03-20 Replace Navi_Roll.brd
    [Navi_Roll.brd]
2023-03-20 Replace Navi_Thunderman.brd
    [Navi_Thunderman.brd]
2023-03-20 Replace Navi_Windman.brd
    [Navi_Windman.brd]
2023-03-20 Replace Navi_Woodman.brd
    [Navi_Woodman.brd]
2023-03-20 Replace Otenko.brd
    [Otenko.brd]
2023-03-20 Replace Air_Wheel_3.brd
    [Air_Wheel_3.brd]
2023-03-20 Replace BugBomb.brd
    [BugBomb.brd]
2023-03-20 Replace Dark_Wide.brd
    [Dark_Wide.brd]
2023-03-20 Replace Dark_Circle.brd
    [Dark_Circle.brd]
2023-03-20 Replace Dark_Lance.brd
    [Dark_Lance.brd]
2023-03-20 Replace Dark_Meteors.brd
    [Dark_Meteors.brd]
2023-03-20 Replace Dark_Tornado.brd
    [Dark_Tornado.brd]
2023-03-20 Replace Discord.brd
    [Discord.brd]
2023-03-20 Replace Django_V2.brd
    [Django_V2.brd]
2023-03-20 Replace Django_V3.brd
    [Django_V3.brd]
2023-03-20 Replace Flame_Sword.brd
    [Flame_Sword.brd]
2023-03-20 Replace GunDelSol_3.brd
    [GunDelSol_3.brd]
2023-03-20 Replace Hakushaku_EX.brd
    [Hakushaku_EX.brd]
2023-03-20 Replace Hakushaku_SP.brd
    [Hakushaku_SP.brd]
2023-03-20 Replace Heat_Dragon.brd
    [Heat_Dragon.brd]
2023-03-20 Replace Panel_Steal.brd
    [Panel_Steal.brd]
2023-03-20 Replace Train_Arrow_3.brd
    [Train_Arrow_3.brd]
2023-03-29 Replace beast_navi_small_ic_curved_repro.brd
    [beast_navi_small_ic_curved_repro.brd]
2023-04-25 Delete Battle_Chip_Solid_v2.STL
    errors
    [Battle_Chip_Solid_v2.STL]
